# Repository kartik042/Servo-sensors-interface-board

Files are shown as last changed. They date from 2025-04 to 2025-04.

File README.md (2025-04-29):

This interface board uses Arduino board to control servo motors and has the following features:
1. Read data from airflow sensors
2. Uses 12VDC input
3. Has a TFT screen to display sensor values and UI elements to control the motors.
4. LDO voltage regulator MIC2940A to convert 12VDC to 3.3VDC
5. TMUX1208PWR multiplexer for data and clock signals
6. Pressure sensor that measures static pressure and the data is available on the display





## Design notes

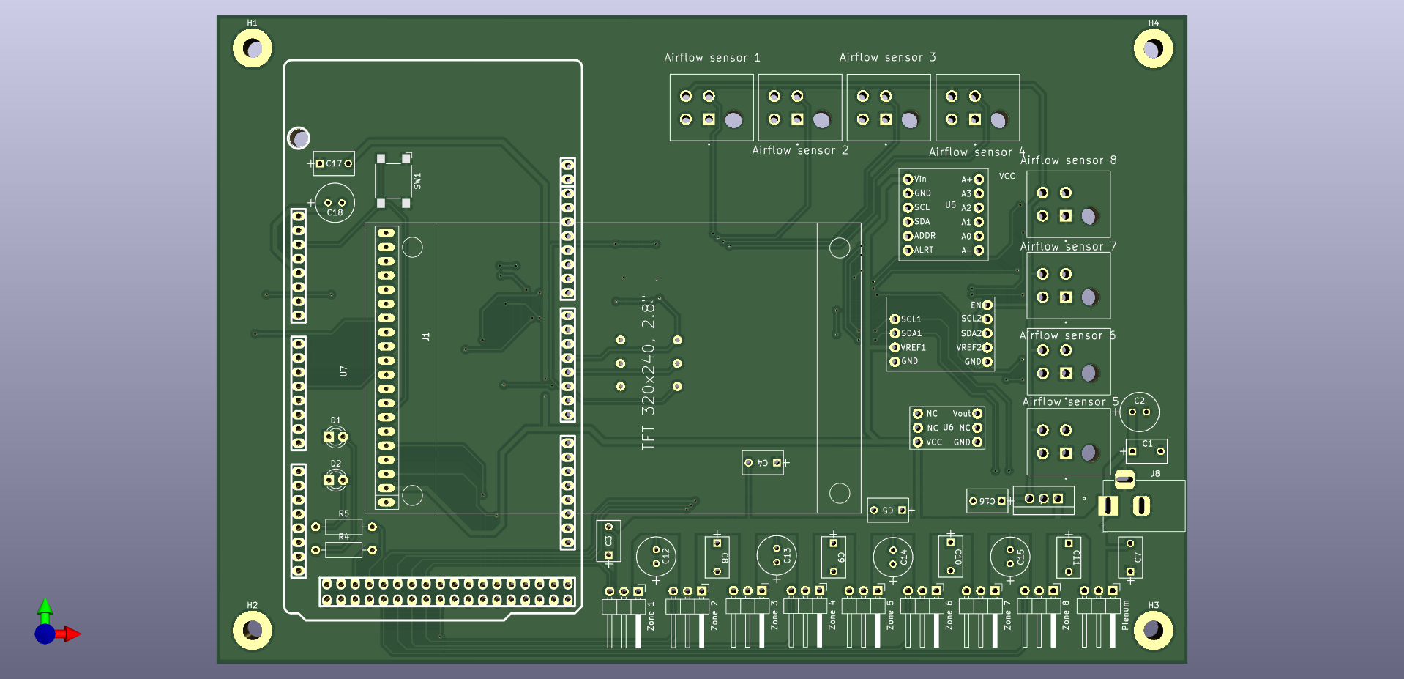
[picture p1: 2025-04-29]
PCB front view.png

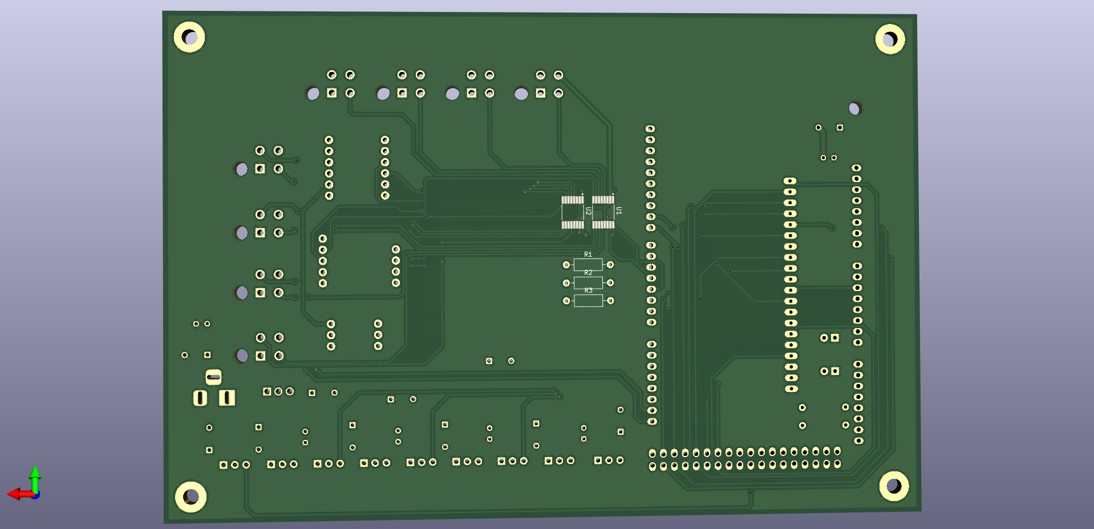
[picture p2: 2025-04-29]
PCB back view.png

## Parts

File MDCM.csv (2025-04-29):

Source: | C:\Users\kxd19\OneDrive - Lennox International, Inc\Documents\PCB Designs\MDCM\Rev 3\MDCM\MDCM.kicad_sch
Date: | 5/14/2024 12:34
Tool: | Eeschema 7.0.7
Generator: | C:\Program Files\KiCad\7.0\bin\scripting\plugins/bom_csv_grouped_by_value.py
Component Count: | 56
Collated Components:
Item | Qty | Reference(s) | Value | Part | LibPart | Footprint | Datasheet | DNP | Check_prices | Description | DigiKey_Part_Number | MF | MP | Package | Purchase-URL | SnapEDA_Link
1 | 2 | C1, C16 | 1uF |  | Device:C | Cap 1uF:CAP_C330C_MR_X7R_KEM | ~
2 | 6 | C2, C12, C13, C14, C15, C18 | 100uF |  | Device:C | Cap 100uF:CAP_YX_6P3X11_RUB | ~
3 | 10 | C3, C4, C5, C6, C7, C8, C9, C10, C11, C17 | 0.1uF |  | Device:C | Cap 1uF:CAP_C330C_MR_X7R_KEM | ~
4 | 2 | D1, D2 | LED |  | Device:LED | LED_THT:LED_D3.0mm | ~
6 | 1 | J1 | Arduino_Mega_Header | Male 0.100" straight header | w_connectors:Arduino_Mega_Header | w_conn_misc:arduino_mega_header
7 | 1 | J2 | Airflow sensor 1 |  | Connector:Screw_Terminal_01x04 | Downloads:TE_1-770174-1 | ~
8 | 1 | J3 | Airflow sensor 2 |  | Connector:Screw_Terminal_01x04 | Downloads:TE_1-770174-1 | ~
9 | 1 | J4 | Airflow sensor 3 |  | Connector:Screw_Terminal_01x04 | Downloads:TE_1-770174-1 | ~
10 | 1 | J5 | Airflow sensor 4 |  | Connector:Screw_Terminal_01x04 | Downloads:TE_1-770174-1 | ~
11 | 1 | J6 | Motor Connector 1 | Male 0.100" angled header | Connector:Conn_01x03_Pin | Connector_PinHeader_2.54mm:PinHeader_1x03_P2.54mm_Horizontal | ~
12 | 1 | J7 | Motor Connector 2 | Male 0.100" angled header | Connector:Conn_01x03_Pin | Connector_PinHeader_2.54mm:PinHeader_1x03_P2.54mm_Horizontal | ~
13 | 1 | J8 | Barrel_Jack_Switch_Pin3Ring |  | Connector:Barrel_Jack_Switch_Pin3Ring | Connector_BarrelJack:BarrelJack_Horizontal | ~
14 | 1 | J9 | Motor Connector 3 | Male 0.100" angled header | Connector:Conn_01x03_Pin | Connector_PinHeader_2.54mm:PinHeader_1x03_P2.54mm_Horizontal | ~
15 | 1 | J10 | Motor Connector 4 | Male 0.100" angled header | Connector:Conn_01x03_Pin | Connector_PinHeader_2.54mm:PinHeader_1x03_P2.54mm_Horizontal | ~
24 | 1 | J19 | Motor Connector 9 | Male 0.100" angled header | Connector:Conn_01x03_Pin | Connector_PinHeader_2.54mm:PinHeader_1x03_P2.54mm_Horizontal | ~
25 | 3 | R1, R2, R3 | 10K |  | Device:R | Resistor_THT:R_Axial_DIN0207_L6.3mm_D2.5mm_P10.16mm_Horizontal | ~
26 | 2 | R4, R5 | 220ohms |  | Device:R | Resistor_THT:R_Axial_DIN0207_L6.3mm_D2.5mm_P10.16mm_Horizontal | ~
27 | 1 | SW1 | SW_Omron_B3FS | SMD switch | Switch:SW_Omron_B3FS | Button_Switch_SMD:SW_SPST_Omron_B3FS-100xP | https://omronfs.omron.com/en_US/ecb/products/pdf/en-b3fs.pdf
28 | 2 | U1, U2 | TMUX1208PWR |  | TMUX1208PWR:TMUX1208PWR | TMUX1208PWR:SOP65P640X120-16N |  |  | https://www.snapeda.com/parts/TMUX1208PWR/Texas+Instruments/view-part/?ref=eda | 5-V, 8:1, 1-channel general-purpose analog multiplexer with 1.8-V input logic | 296-51847-2-ND | Texas Instruments | TMUX1208PWR | TSSOP-16 Texas Instruments | https://www.snapeda.com/api/url_track_click_mouser/?unipart_id=3223186&manufacturer=Texas Instruments&part_name=TMUX1208PWR&search_term=None | https://www.snapeda.com/parts/TMUX1208PWR/Texas+Instruments/view-part/?ref=snap
29 | 1 | U3 | Level Shifter | Female 0.100" straight header | w_connectors:Level_Shifter | w_conn_misc:Level Shifter
30 | 1 | U4 | MIC2940A-3.3WT |  | 2023-09-26_16-52-27:MIC2940A-3.3WT | footprints:TO220-3LD-PL-1_MCH | MIC2940A-3.3WT
31 | 1 | U5 | 12 Bit ADC_1 | Female 0.100" straight header | w_connectors:12_bit_ADC_1 | w_conn_misc:12 Bit ADC_1
32 | 1 | U6 | Pressure Sensor | Female 0.100" straight header | w_connectors:Pressure_Sensor | w_conn_misc:Pressure Sensor
33 | 1 | U7 | TFT_320x240 | Female 0.100" straight header | tft_320x240:TFT_320x240 | Downloads:TFT-320x240

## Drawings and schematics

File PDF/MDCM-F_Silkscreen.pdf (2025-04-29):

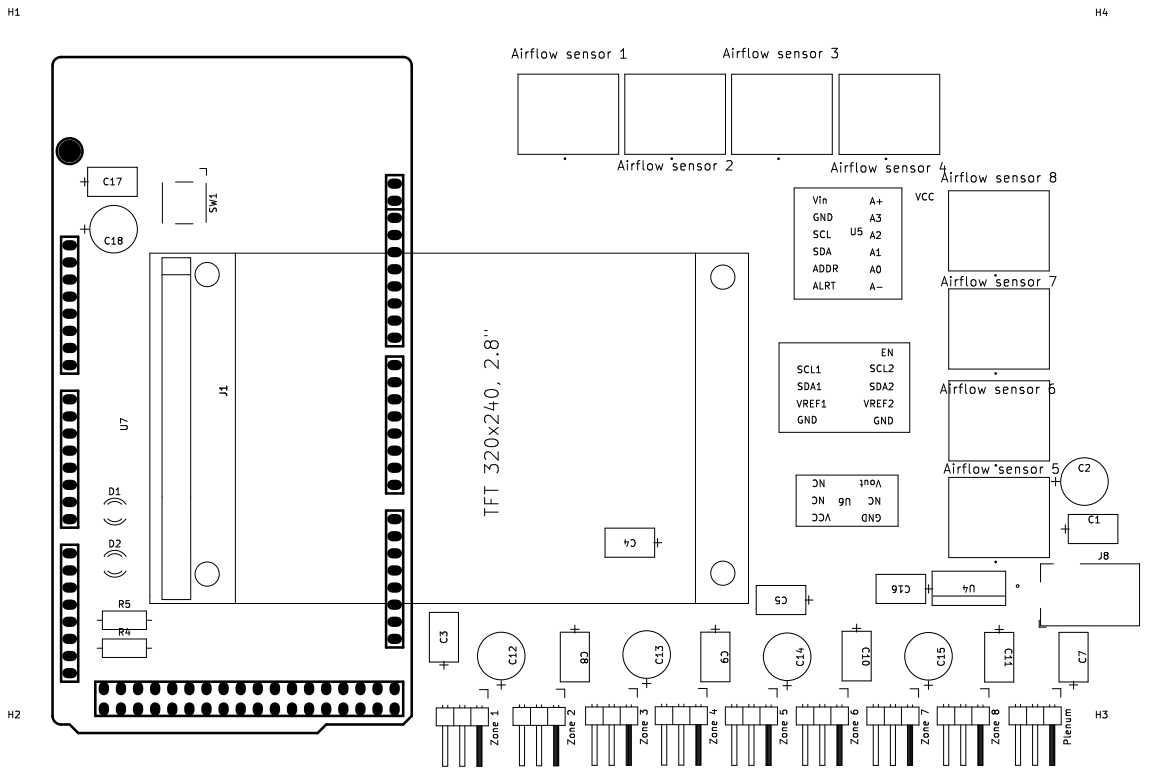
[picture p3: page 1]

C7 Zone 6 C10 J1 C11 Airflow sensor 8 Zone 4 Airflow sensor 7 Zone 8 U4 C8 Zone 3

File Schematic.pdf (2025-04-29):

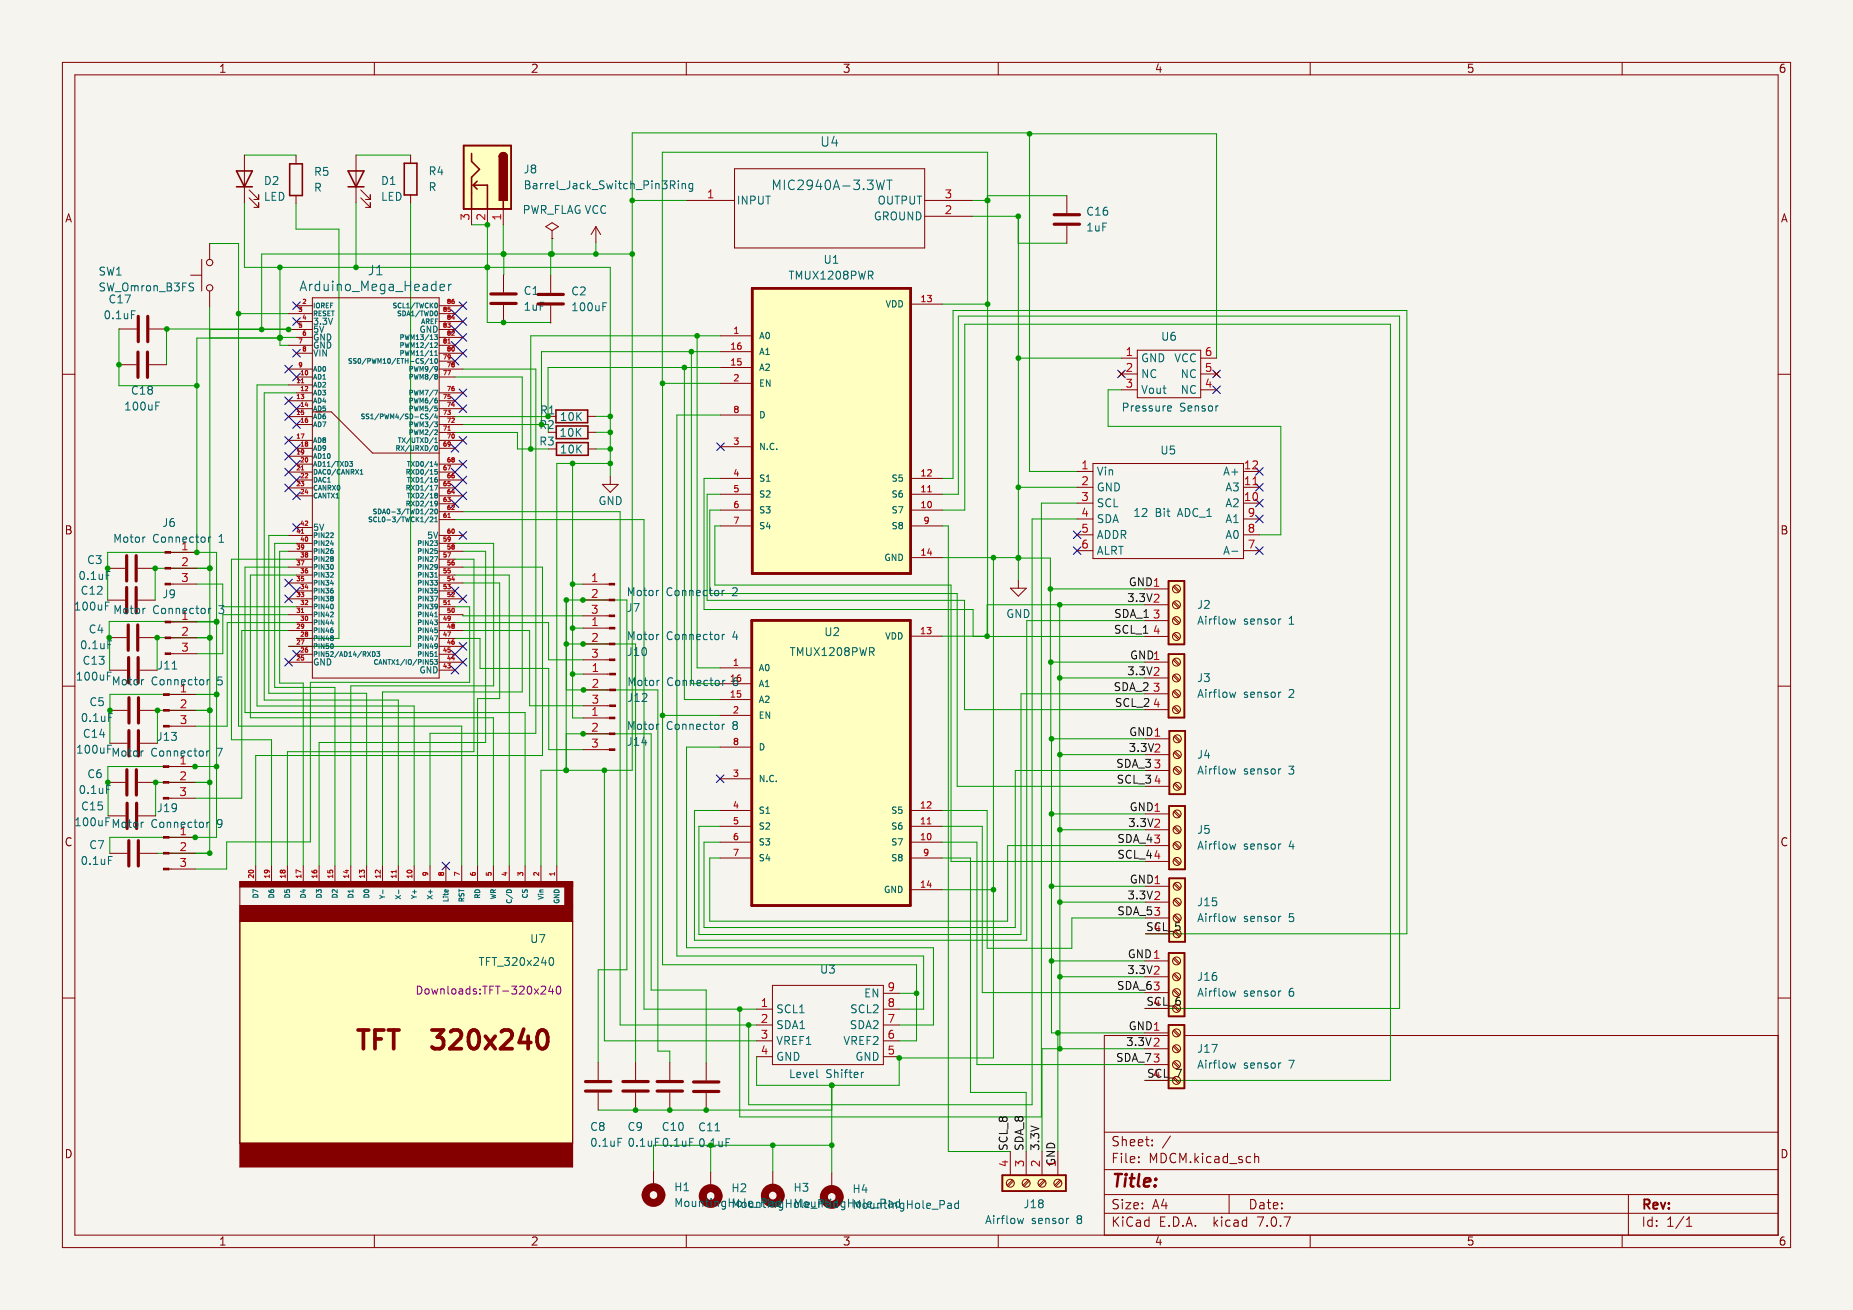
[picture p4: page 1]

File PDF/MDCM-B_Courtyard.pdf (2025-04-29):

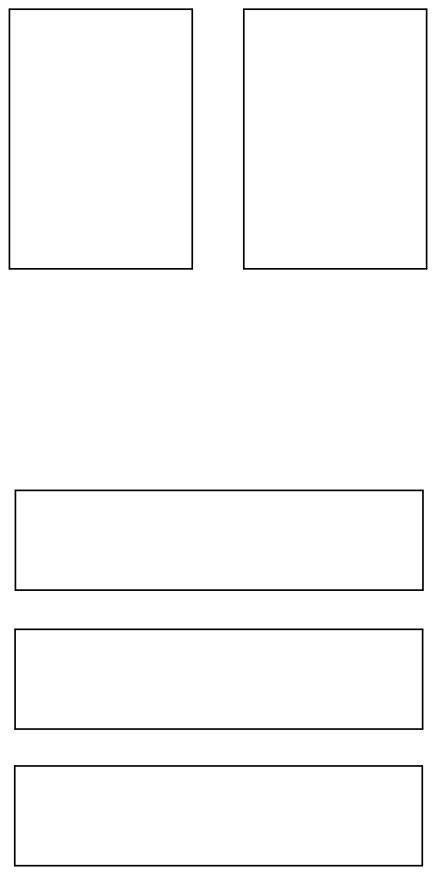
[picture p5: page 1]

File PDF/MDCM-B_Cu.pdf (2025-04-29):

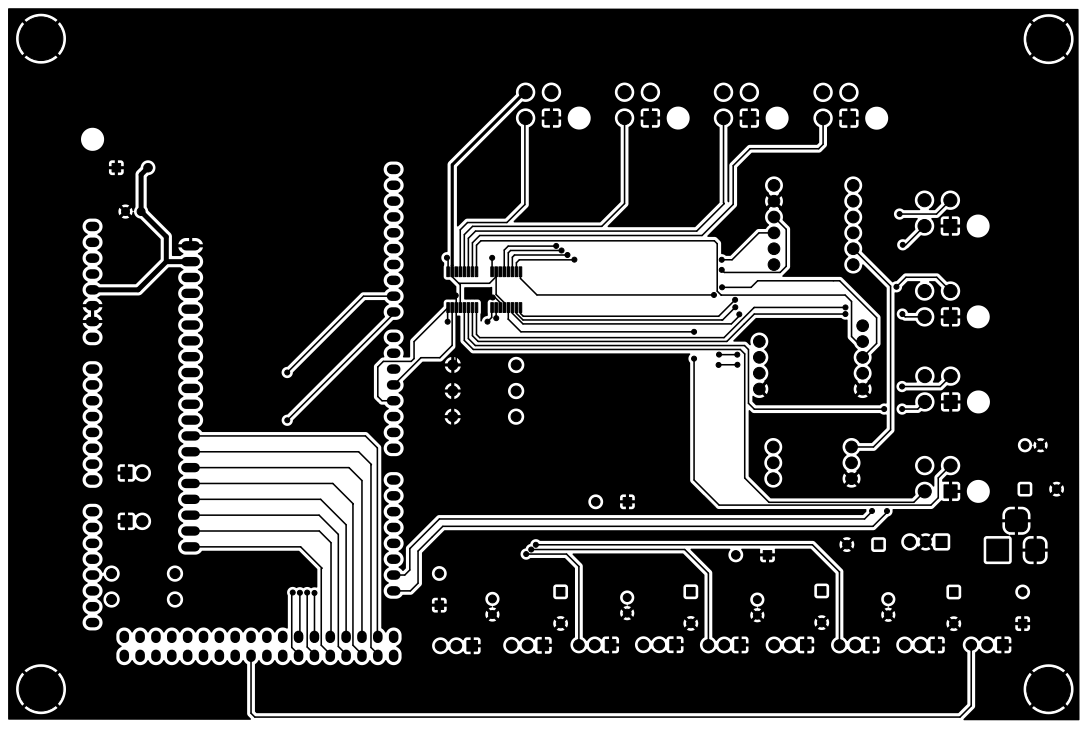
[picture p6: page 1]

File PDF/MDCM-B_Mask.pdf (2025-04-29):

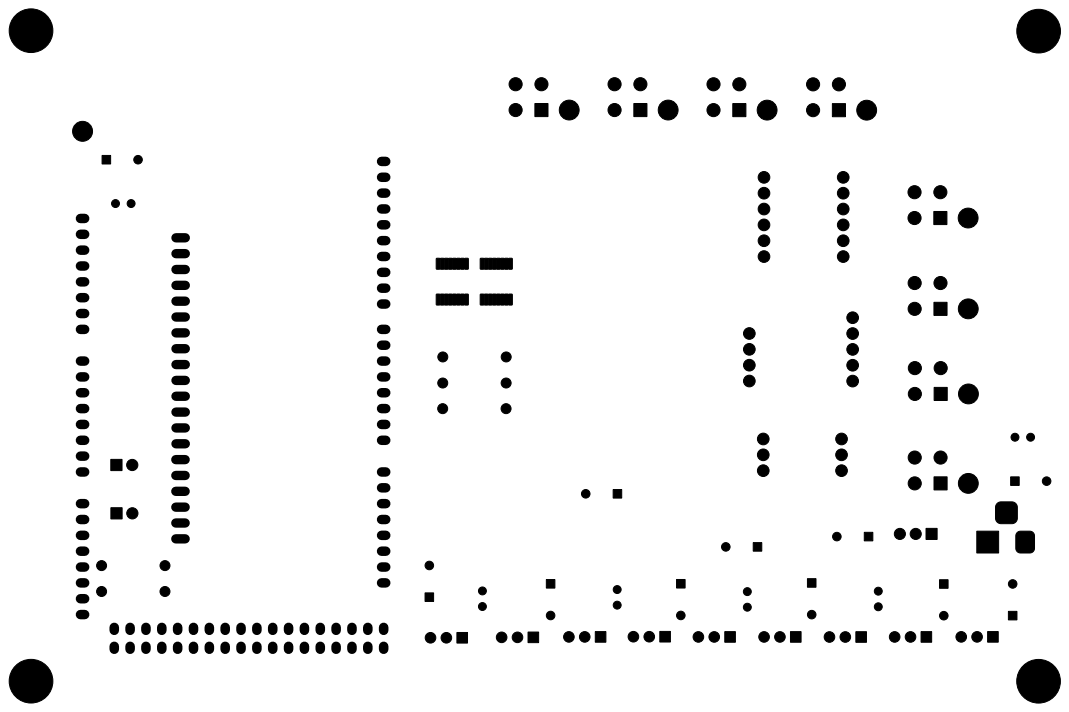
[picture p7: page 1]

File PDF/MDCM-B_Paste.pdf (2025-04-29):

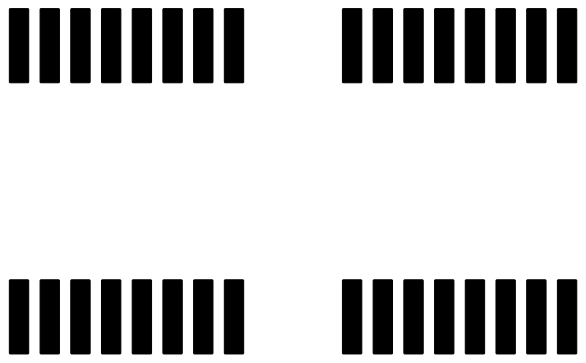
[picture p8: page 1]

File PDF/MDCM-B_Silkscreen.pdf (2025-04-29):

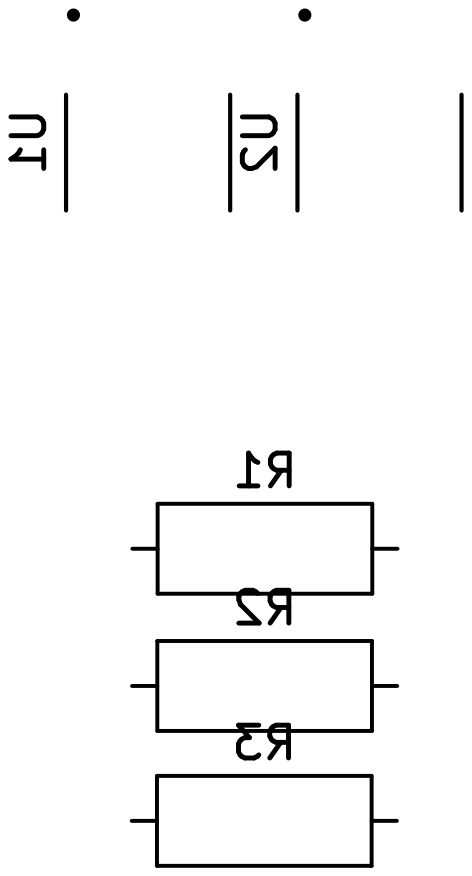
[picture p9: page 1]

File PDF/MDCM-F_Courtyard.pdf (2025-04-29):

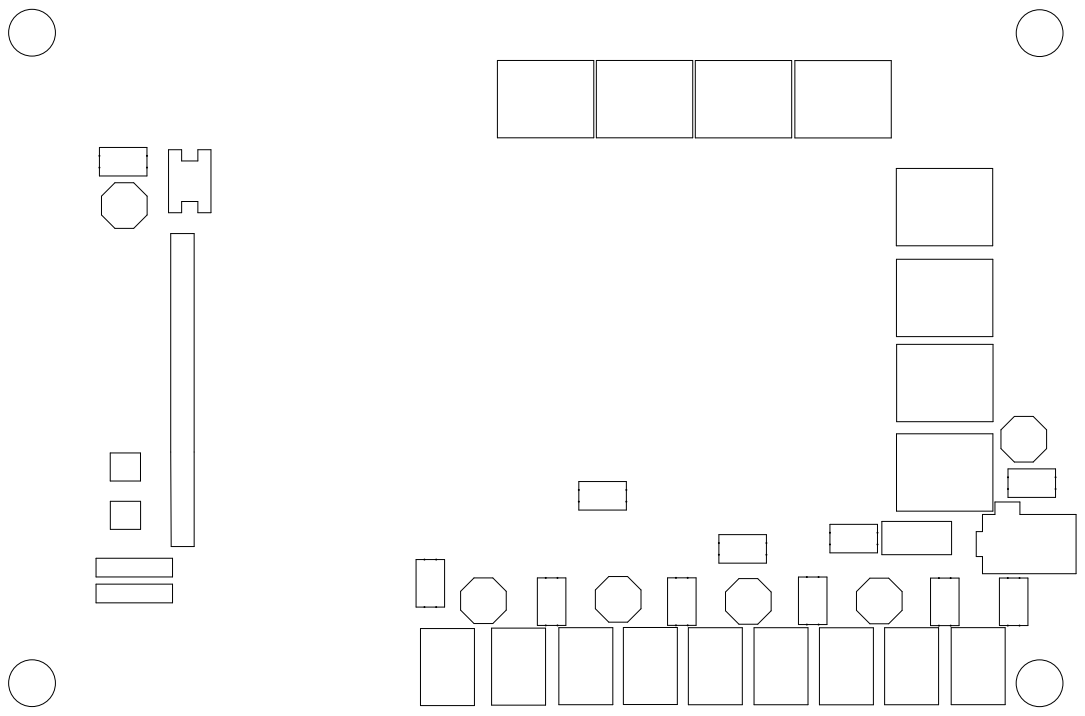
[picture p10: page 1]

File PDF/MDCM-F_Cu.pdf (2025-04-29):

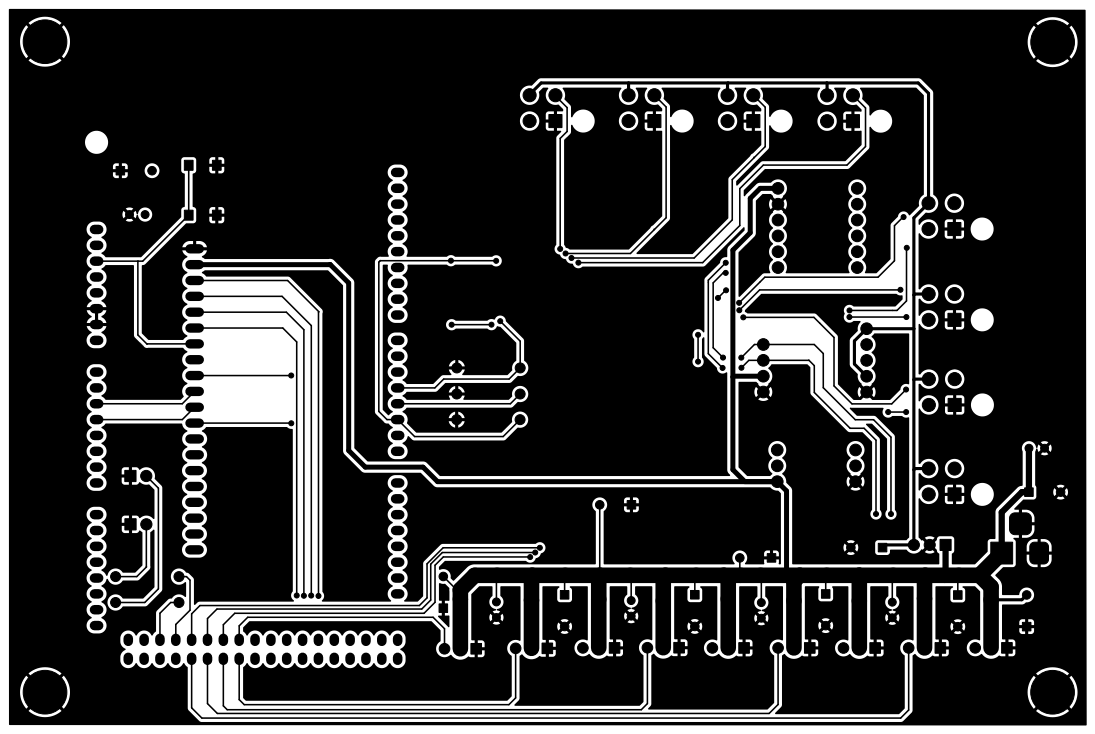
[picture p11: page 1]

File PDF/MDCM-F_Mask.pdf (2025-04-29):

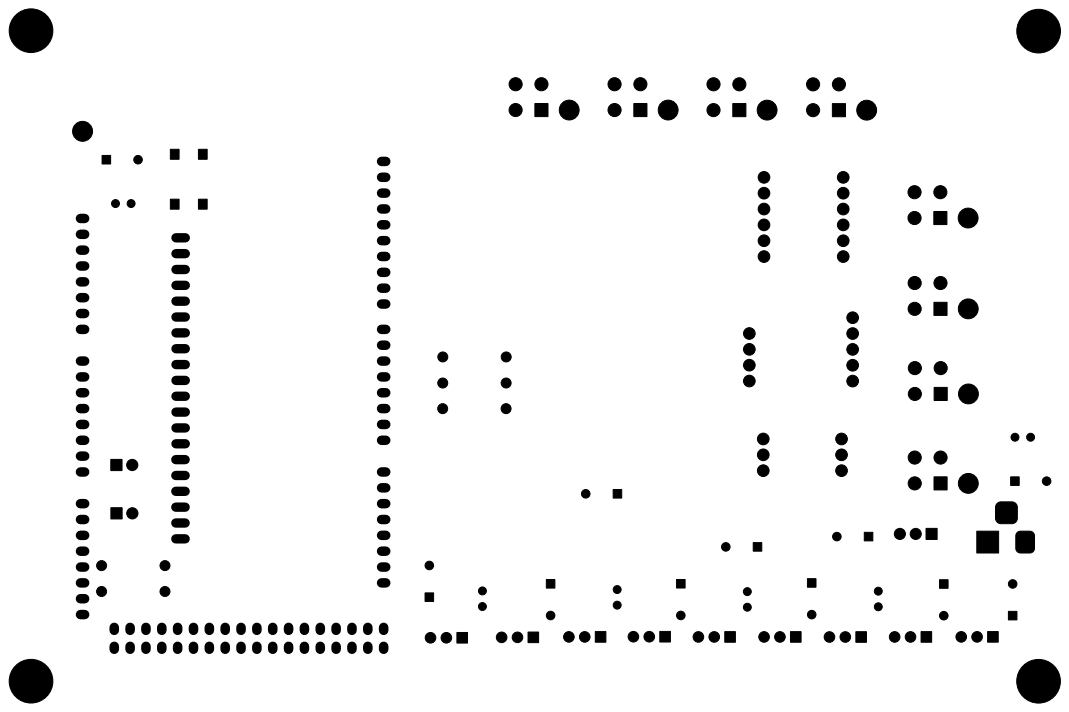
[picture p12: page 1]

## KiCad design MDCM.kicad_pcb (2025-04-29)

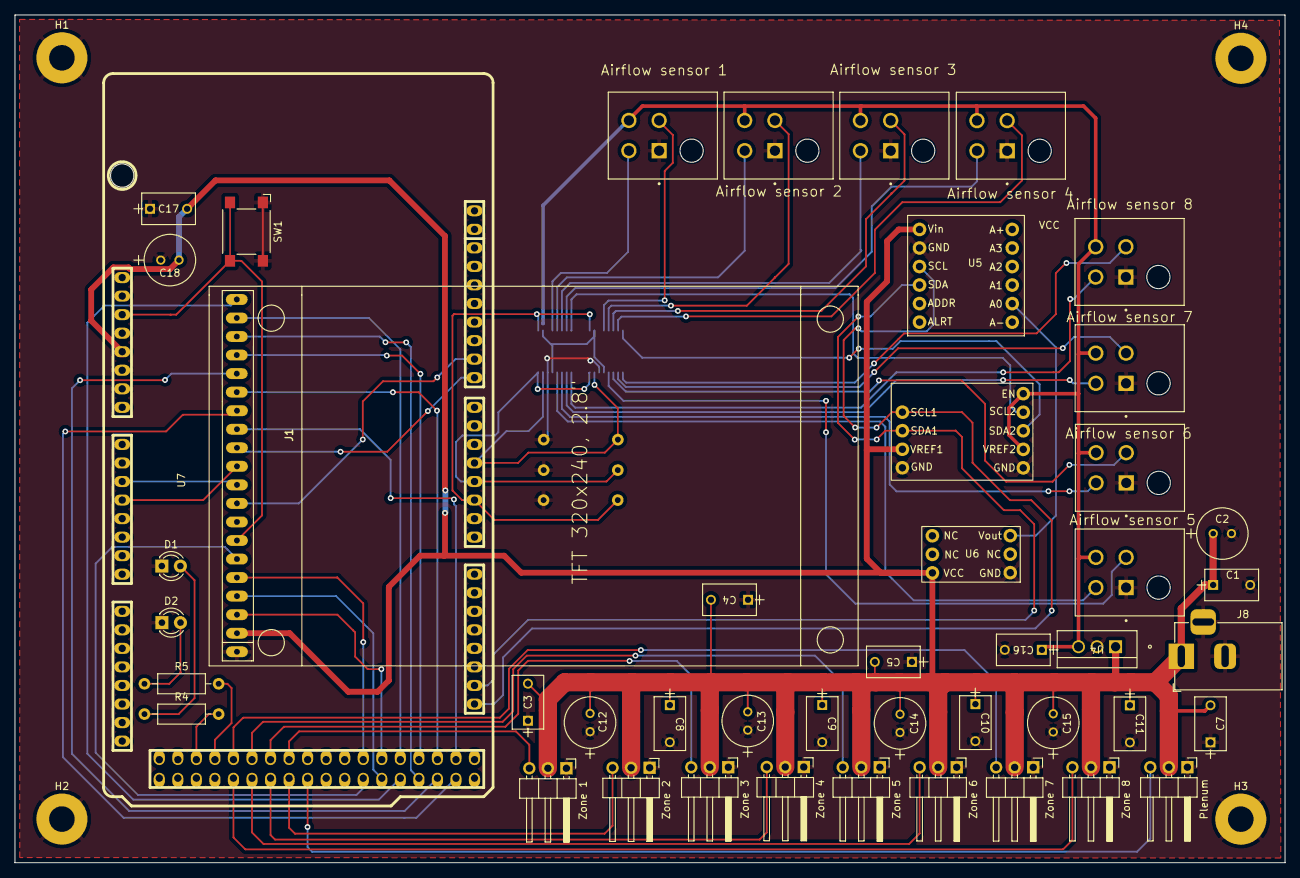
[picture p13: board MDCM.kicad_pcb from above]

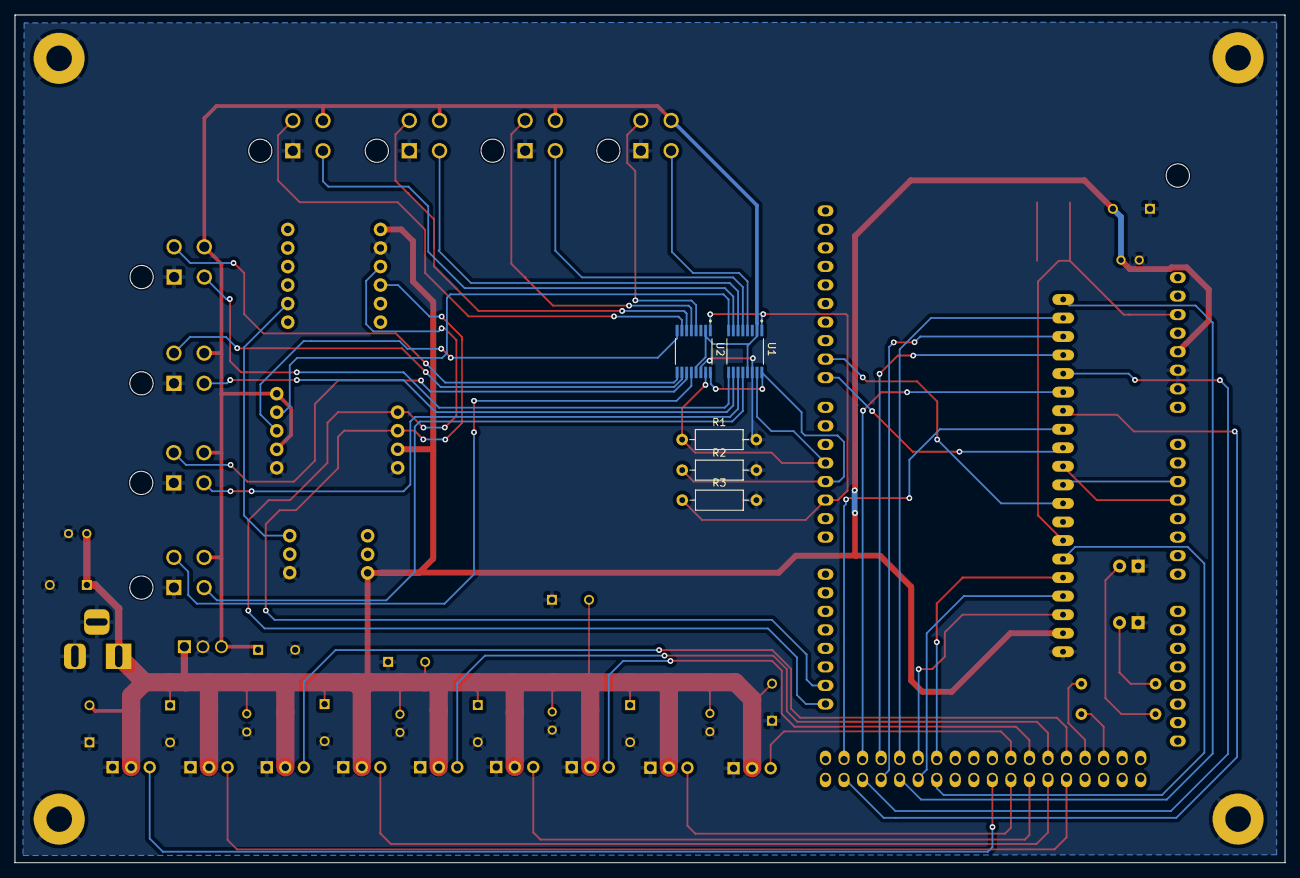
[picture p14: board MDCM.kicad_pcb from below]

Board: 2 copper layers, 174.0 x 116.1 mm, 55 parts (5 on the bottom side), 57 nets.

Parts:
Airflow sensor 1: J2; TE_1-770174-1
Airflow sensor 2: J3; TE_1-770174-1
Airflow sensor 3: J4; TE_1-770174-1
Airflow sensor 4: J5; TE_1-770174-1
Airflow sensor 5: J15; TE_1-770174-1
Airflow sensor 6: J16; TE_1-770174-1
Airflow sensor 7: J17; TE_1-770174-1
Airflow sensor 8: J18; TE_1-770174-1
C1, C16: 1uF; CAP_C330C_MR_X7R_KEM
C2, C12, C13, C14, C15, C18: 100uF; CAP_YX_6P3X11_RUB
C3, C4, C5, C7, C8, C9, C10, C11, C17: 0.1uF; CAP_C330C_MR_X7R_KEM
D1, D2: LED; LED_D3.0mm
H1, H2, H3, H4: MountingHole_Pad; MountingHole_3.5mm_Pad
J1: Arduino_Mega_Header; arduino_mega_header
J8: Barrel_Jack_Switch_Pin3Ring; BarrelJack_Horizontal
Plenum: Motor Connector 9; PinHeader_1x03_P2.54mm_Horizontal
R1, R2, R3: 10K; R_Axial_DIN0207_L6.3mm_D2.5mm_P10.16mm_Horizontal
R4, R5: R; R_Axial_DIN0207_L6.3mm_D2.5mm_P10.16mm_Horizontal
SW1: SW_Omron_B3FS; SW_SPST_Omron_B3FS-100xP
U1, U2: TMUX1208PWR; SOP65P640X120-16N
U3: Level Shifter
U4: MIC2940A-3.3WT; TO220-3LD-PL-1_MCH
U5: 12 Bit ADC_1
U6: Pressure Sensor
U7: TFT_320x240; TFT-320x240
Zone 1: Motor Connector 1; PinHeader_1x03_P2.54mm_Horizontal
Zone 2: Motor Connector 2; PinHeader_1x03_P2.54mm_Horizontal
Zone 3: Motor Connector 3; PinHeader_1x03_P2.54mm_Horizontal
Zone 4: Motor Connector 4; PinHeader_1x03_P2.54mm_Horizontal
Zone 5: Motor Connector 5; PinHeader_1x03_P2.54mm_Horizontal
Zone 6: Motor Connector 6; PinHeader_1x03_P2.54mm_Horizontal
Zone 7: Motor Connector 7; PinHeader_1x03_P2.54mm_Horizontal
Zone 8: Motor Connector 8; PinHeader_1x03_P2.54mm_Horizontal

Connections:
/3.3V: Airflow sensor 1.2, Airflow sensor 2.2, Airflow sensor 3.2, Airflow sensor 4.2, Airflow sensor 5.2, Airflow sensor 6.2, Airflow sensor 7.2, Airflow sensor 8.2, C16.1, U1.2 (EN), U1.13 (VDD), U2.2 (EN), U2.13 (VDD), U3.6 (VREF2), U3.9 (EN), U4.3 (OUTPUT)
/SCL_1: Airflow sensor 1.4, U1.4 (S1)
/SCL_2: Airflow sensor 2.4, U1.5 (S2)
/SCL_3: Airflow sensor 3.4, U1.6 (S3)
/SCL_4: Airflow sensor 4.4, U1.7 (S4)
/SCL_5: Airflow sensor 5.4, U1.12 (S5)
/SCL_6: Airflow sensor 6.4, U1.11 (S6)
/SCL_7: Airflow sensor 7.4, U1.10 (S7)
/SCL_8: Airflow sensor 8.4, U1.9 (S8)
/SDA_1: Airflow sensor 1.3, U2.4 (S1)
/SDA_2: Airflow sensor 2.3, U2.5 (S2)
/SDA_3: Airflow sensor 3.3, U2.6 (S3)
/SDA_4: Airflow sensor 4.3, U2.7 (S4)
/SDA_5: Airflow sensor 5.3, U2.12 (S5)
/SDA_6: Airflow sensor 6.3, U2.11 (S6)
/SDA_7: Airflow sensor 7.3, U2.10 (S7)
/SDA_8: Airflow sensor 8.3, U2.9 (S8)
GND: Airflow sensor 1.1, Airflow sensor 2.1, Airflow sensor 3.1, Airflow sensor 4.1, Airflow sensor 5.1, Airflow sensor 6.1, Airflow sensor 7.1, Airflow sensor 8.1, C1.2, C2.2, C3.1, C4.1, C5.1, C7.1, C8.2, C9.2, C10.2, C11.2, C12.1, C13.1, C14.1, C15.1, C16.2, C17.1, C18.1, D1.1 (K), D2.1 (K), H1.1, H2.1, H3.1, H4.1, J1.6 (GND), J1.7 (GND), J8.2, J8.3, Plenum.1, R1.2, R2.2, R3.2, SW1.1, U1.14 (GND), U2.14 (GND), U3.4 (GND), U3.5 (GND), U4.2 (GROUND), U5.2 (GND), U6.1 (GND), U7.1 (GND), Zone 1.1, Zone 2.1, Zone 3.1, Zone 4.1, Zone 5.1, Zone 6.1, Zone 7.1, Zone 8.1
unnamed: D1.2 (A), R4.1
unnamed: D2.2 (A), R5.1
unnamed: J1.11 (AD2), U7.10 (Y+)
unnamed: J1.12 (AD3), U7.11 (X-)
unnamed: J1.41 (PIN22), U7.13 (D0)
unnamed: J1.59 (PIN23), U7.14 (D1)
unnamed: J1.40 (PIN24), U7.15 (D2)
unnamed: J1.58 (PIN25), U7.16 (D3)
unnamed: J1.39 (PIN26), U7.17 (D4)
unnamed: J1.57 (PIN27), U7.18 (D5)
unnamed: J1.38 (PIN28), U7.19 (D6)
unnamed: J1.56 (PIN29), U7.20 (D7)
unnamed: J1.37 (PIN30), U7.3 (CS)
unnamed: J1.55 (PIN31), U7.4 (C/D)
unnamed: J1.36 (PIN32), U7.5 (WR)
unnamed: J1.54 (PIN33), U7.6 (RD)
unnamed: J1.51 (PIN39), Plenum.3
unnamed: J1.32 (PIN40), Zone 1.3
unnamed: J1.50 (PIN41), Zone 2.3
unnamed: J1.31 (PIN42), Zone 3.3
unnamed: J1.49 (PIN43), Zone 4.3
unnamed: J1.30 (PIN44), Zone 5.3
unnamed: J1.48 (PIN45), Zone 6.3
unnamed: J1.29 (PIN46), Zone 7.3
unnamed: J1.47 (PIN47), Zone 8.3
unnamed: J1.28 (PIN48), R5.2
unnamed: J1.27 (PIN50), R4.2
unnamed: J1.71 (PWM2/2), R3.1, U1.1 (A0), U2.1 (A0)
unnamed: J1.72 (PWM3/3), R2.1, U1.16 (A1), U2.16 (A1)
unnamed: J1.77 (PWM8/8), U7.12 (Y-)
unnamed: J1.78 (PWM9/9), U7.9 (X+)
unnamed: J1.3 (RESET), SW1.2, U7.7 (RST)
unnamed: J1.61 (SCL0-3/TWCK1/21), U3.1 (SCL1), U5.3 (SCL)
unnamed: J1.62 (SDA0-3/TWD1/20), U3.2 (SDA1), U5.4 (SDA)
unnamed: J1.73 (SS1/PWM4/SD-CS/4), R1.1, U1.15 (A2), U2.15 (A2)
unnamed: U1.8 (D), U3.8 (SCL2)
unnamed: U2.8 (D), U3.7 (SDA2)
unnamed: U5.8 (A0), U6.3 (Vout)
VCC: C1.1, C2.1, C3.2, C4.2, C5.2, C7.2, C8.1, C9.1, C10.1, C11.1, C12.2, C13.2, C14.2, C15.2, C17.2, C18.2, J1.5 (5V), J8.1, Plenum.2, U3.3 (VREF1), U4.1 (INPUT), U5.1 (Vin), U6.6 (VCC), U7.2 (Vin), Zone 1.2, Zone 2.2, Zone 3.2, Zone 4.2, Zone 5.2, Zone 6.2, Zone 7.2, Zone 8.2
